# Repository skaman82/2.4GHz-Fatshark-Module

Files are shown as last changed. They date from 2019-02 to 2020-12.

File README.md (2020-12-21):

BUILD LOG: https://github.com/skaman82/2.4GHz-Fatshark-Module/wiki </br> </br>
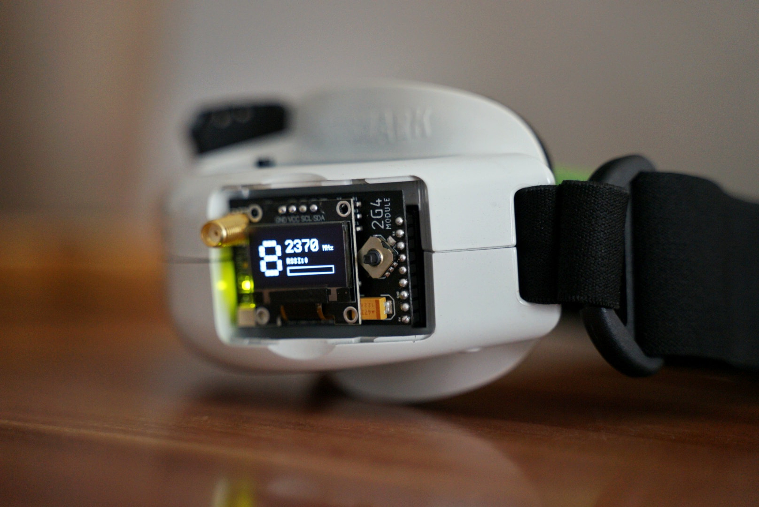
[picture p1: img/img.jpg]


# 2.4GHz-Fatshark-Module
RX28 based Fatshark RX module

- 8 channels (2414, 2432, 2450, 2468, 2490, 2510, 2390, 2370 MHz)
- RSSI display
- Fatshark button control
- Bandscan
- Finder mode
- RSSI calibration
- OSD menus
- OLED screen

Tested with following VTX models:</br>
• TBS Unify 2G4</br>
• Lawmate 2.4</br>
• FuriousFPV 2.4 VTX</br>
• Cheap low power chinese transmitter modules </br>
(no audio compatibility issues unlike the latest RX 2.4 module on the market)

# OPERATION
<b>HOME SCREEN:</b> You can change the channels by pressing the UP/DOWN keys - it works also with the google buttons (if the feature is active). If using the joystick you have to press UP/DOWN once to bring the OSD up - then you can change the channel. After no button press is registered the OSD will automatically disappear. </br>
</br>
By pressing the CENTER button you can bring up the <b>MENU</b>. With UP/DOWN you can switch between different menu items. Select EXIT to return to the home screen.</br>
</br>
<b>GOGGLE CONTROL:</b> Enables fatshark button control.</br>
</br>
<b>BANDSCAN:</b> Scans all channels and displays the RSSI values in a graph.</br>
</br>
<b>LOCK MODE:</b> If activated (lock icon in the home screen) the module will lock up after approx. 10 seconds. All controls are disabled to prevent chanel changes on acidental button press. You can temporarily UNLOCK the module by pressing the CENTER button for 3-5 seconds (the lock icon will open). After unlocking the module it will return to locked state after approx. 10 seconds.</br>
</br>
<b>FIND MODE:</b>Will show the RSSI value in a BAR (oled) or a plot (OSD). Depending on the RSSI value the beeper will beep more often and the OSD LED will blink as well indicating the direction. You can change the channel in the FIND MODE - so be sure you have the correct one. Use a directional antenna to find your model with this function.</br>
</br>
<b>AUTOSEARCH:</b> Press the CENTER button for 2 seconds to call the autosearch function. Autosearch will find the strongest channel and switch to it automatically.</br>
</br>
<b>CALIBRATION:</b> You have to run calibration to have the correct RSSI values. Just follow the instructions in the wizzard.</br>

# UPDATING THE FIRMWARE
You will need a FTDI to USB adapter to upload the module firmware. You may need to install the FTDI driver for it. Set the FTDI to 5V.

Steps to upload new firmware
1. Install Arduino IDE
2. Install the Arduino Libraries from the "Libs" folder.
3. Install the MightyCore hardware package from here: https://github.com/MCUdude/MightyCore (just follow the instructions)
4. Download the firmware and open the Code.INO file from the "Code" folder in Arduino
5. Select the hardware settings in Arduino IDE as shown in the image below
6. Connect the FTDI tool according to the plug pinout as shown in the picture and select the COM port in Arduino IDE
7. If you have the rev 06 PCB open the JUMP1 jumper on the PCB to upload code (solder it together after your upload is done).
8. Upload the code </br>
YOU ARE DONE :)

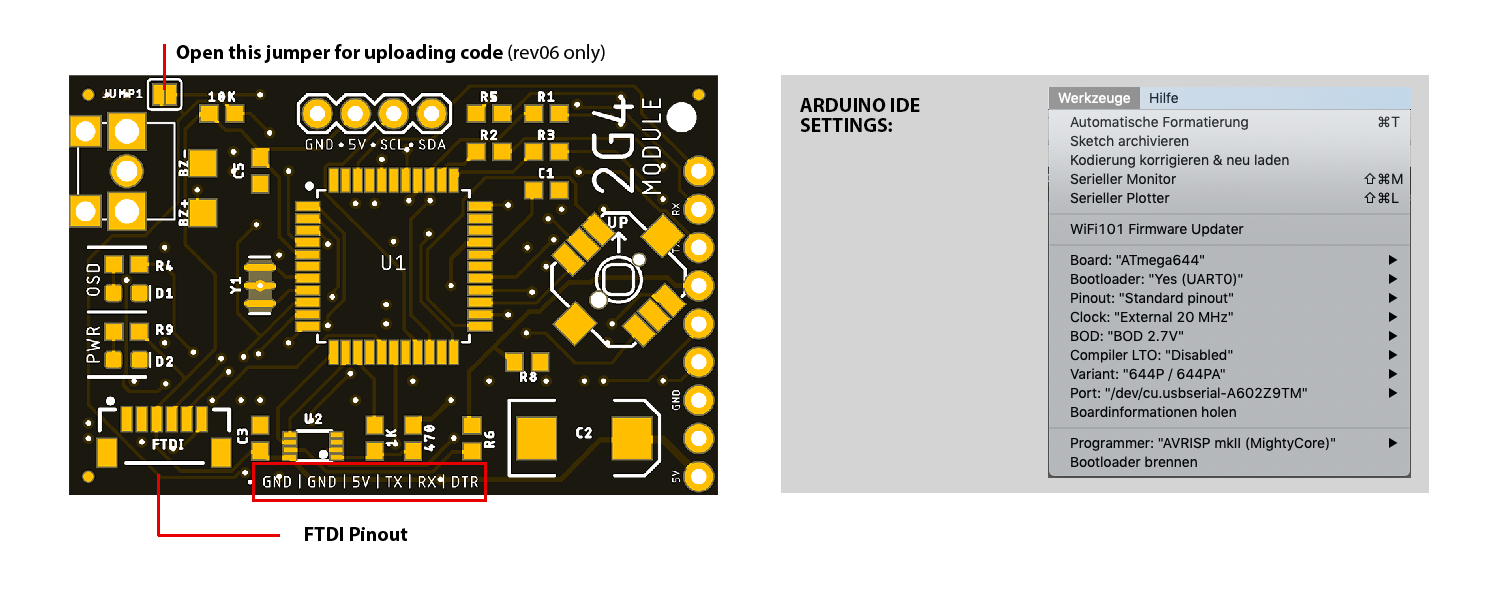
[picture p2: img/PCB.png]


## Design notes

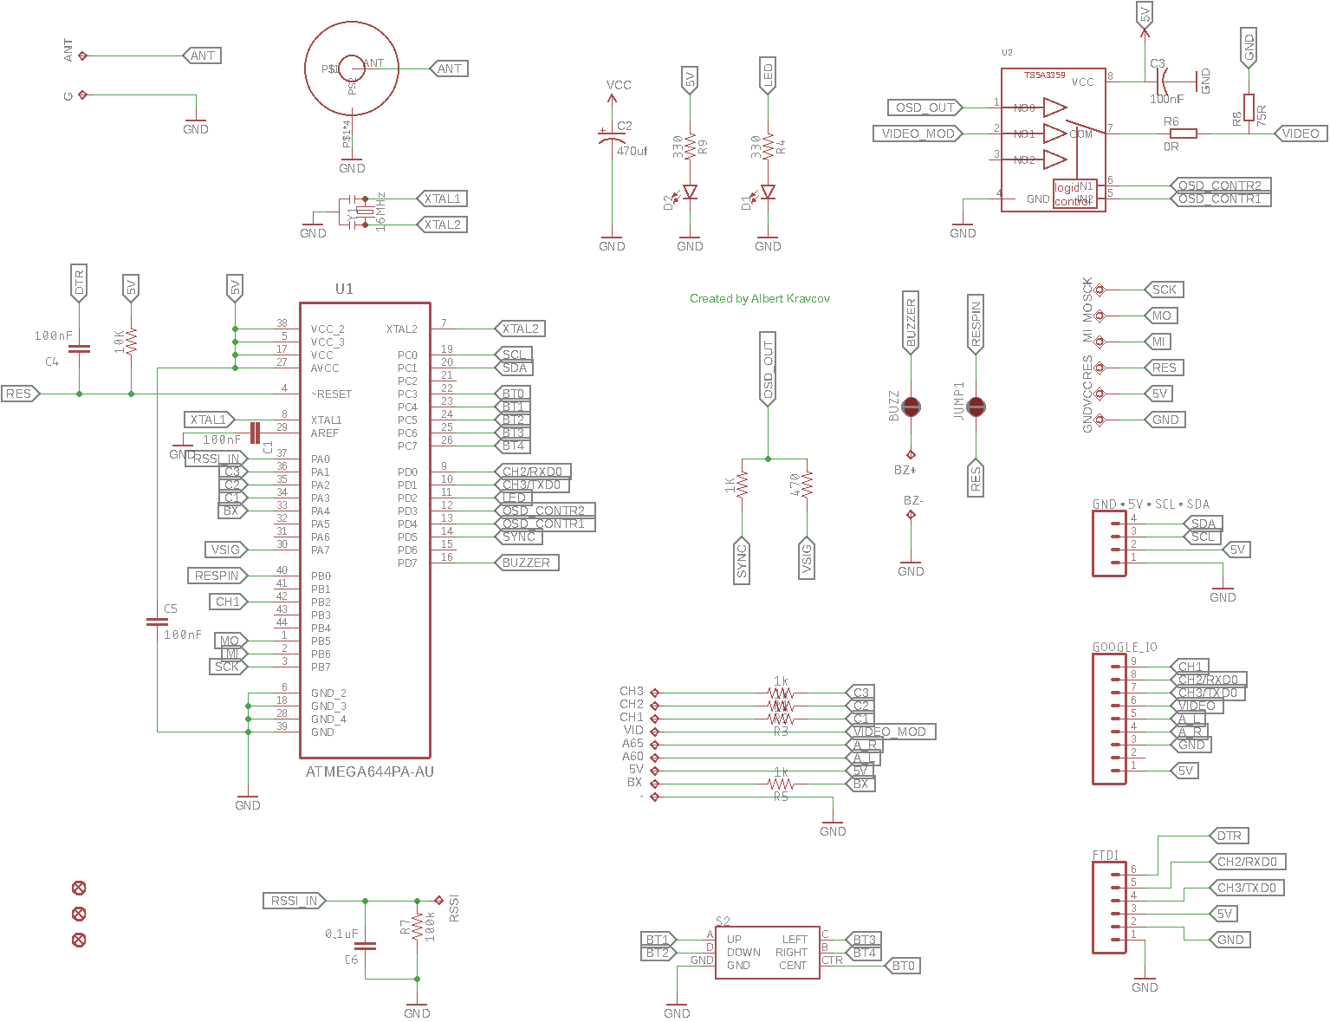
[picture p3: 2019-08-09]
img/schematic rev06.png

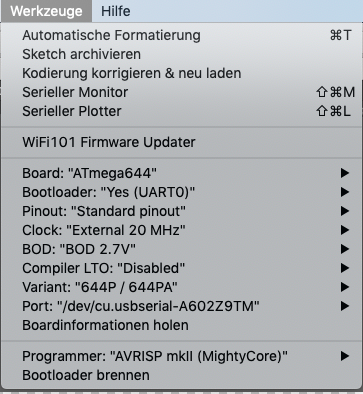
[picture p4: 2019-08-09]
img/arduino_settings.png

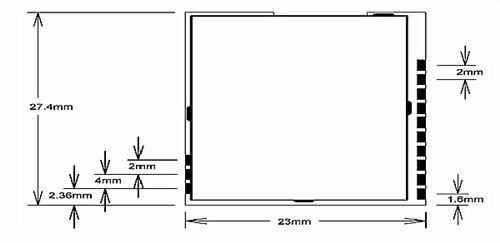
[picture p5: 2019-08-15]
Documents/RX2189 -90db EOL no rssi/HT19IRYFRXdXXagOFbXS.jpg

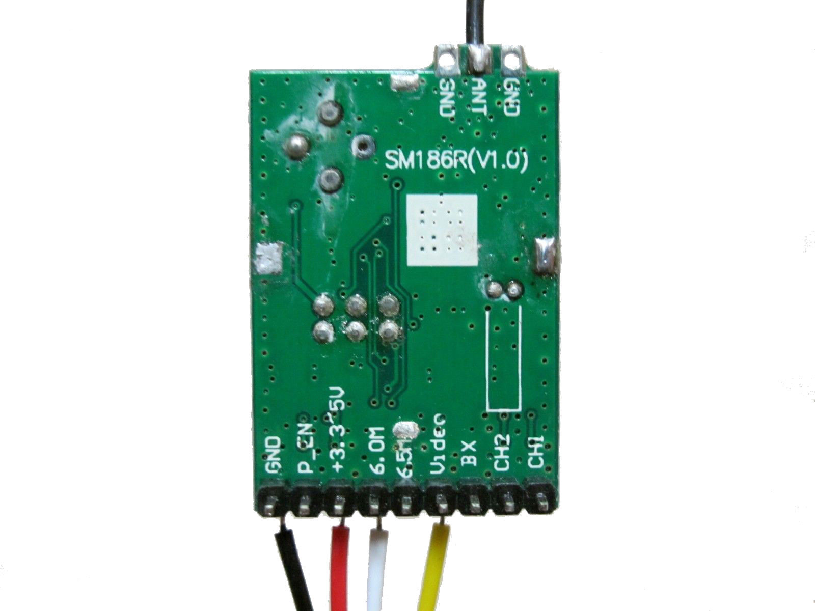
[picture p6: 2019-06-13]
Documents/SM186R -90db no rssi/s-l1600.jpg

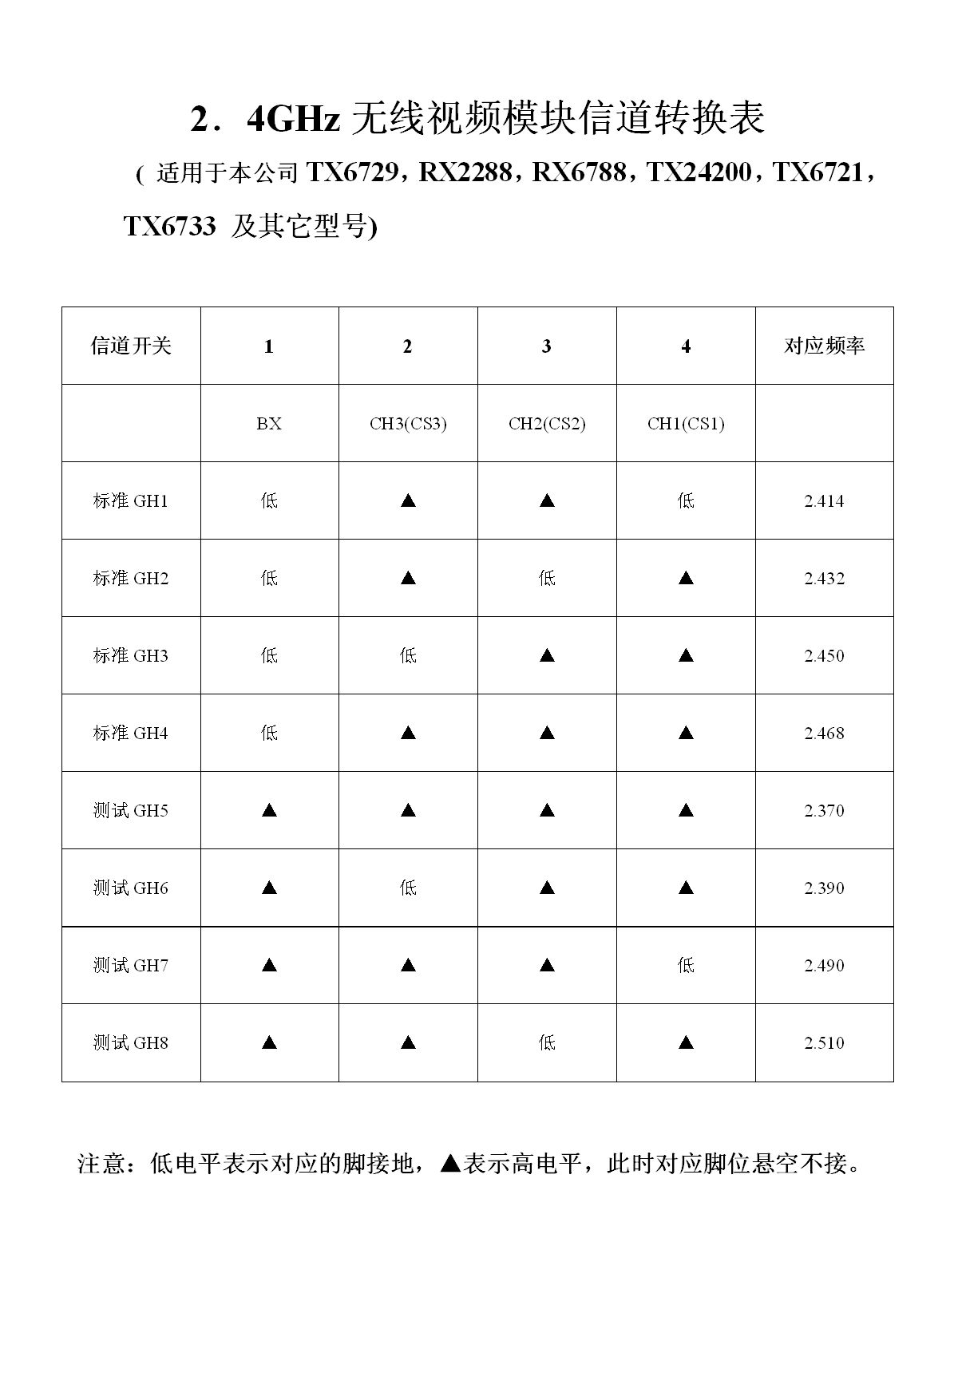
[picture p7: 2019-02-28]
Documents/RX228D -90db VID only - not compatible/2.4G信道表.jpg

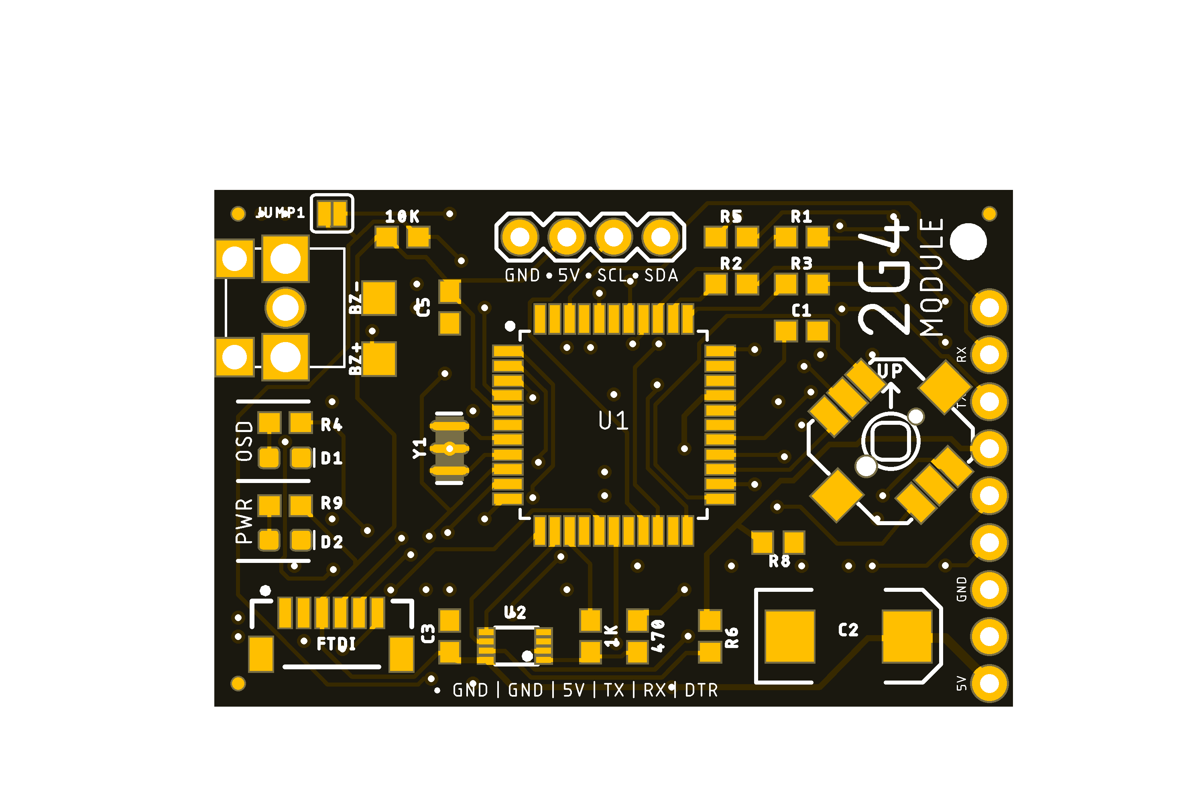
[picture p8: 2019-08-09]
pcb/module S-RX28_rev06 t.png

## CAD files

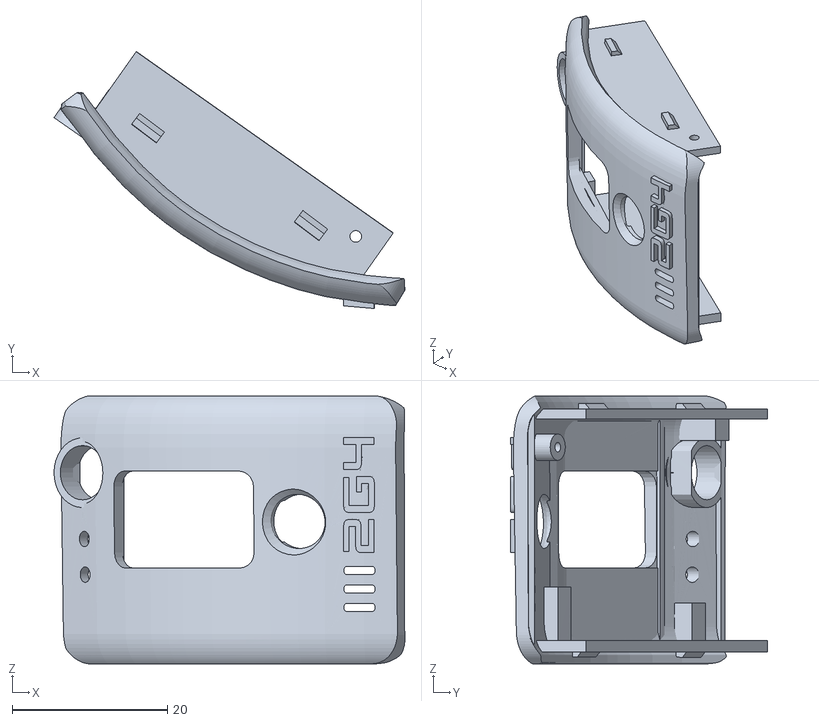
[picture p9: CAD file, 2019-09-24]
Cover/Module_door_V2.stl
45.3 x 33.2 x 34.5

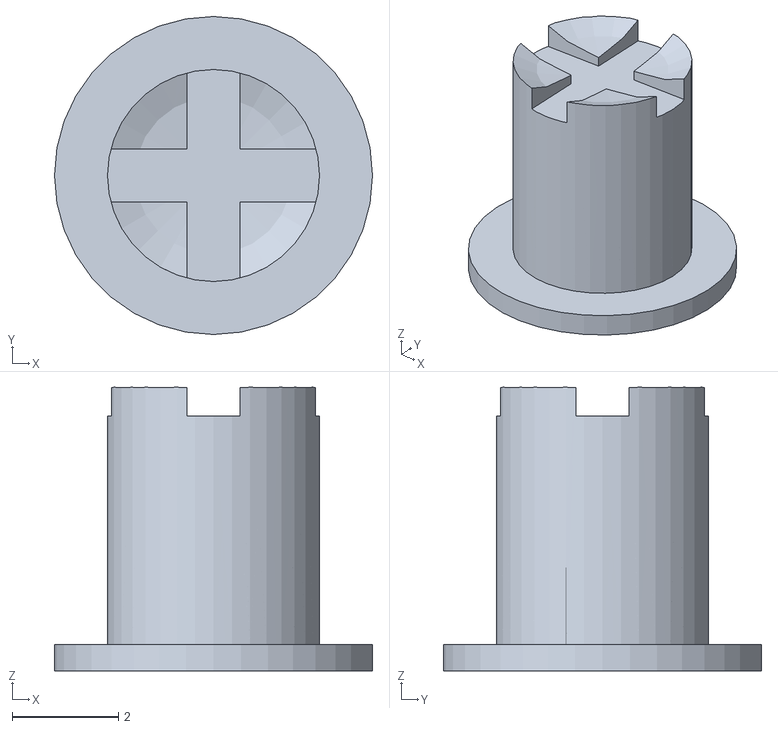
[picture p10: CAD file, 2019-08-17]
Cover/Module_door_button.stl
6.00 x 6.00 x 5.35

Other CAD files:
Cover/Module_door_V1.stl

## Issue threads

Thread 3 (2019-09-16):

Part list

Scavanger, 2019-09-16:
Hey, great project.
A complete partlist would be very helpful, especially display (Geekcreit 0.96" oled i2c, I guess), 5 way switch and SMA plug.
Thanks!

skaman82, 2019-09-19:
Thanks, you can find the complete list in the Wiki.

Closed 2019-09-19.

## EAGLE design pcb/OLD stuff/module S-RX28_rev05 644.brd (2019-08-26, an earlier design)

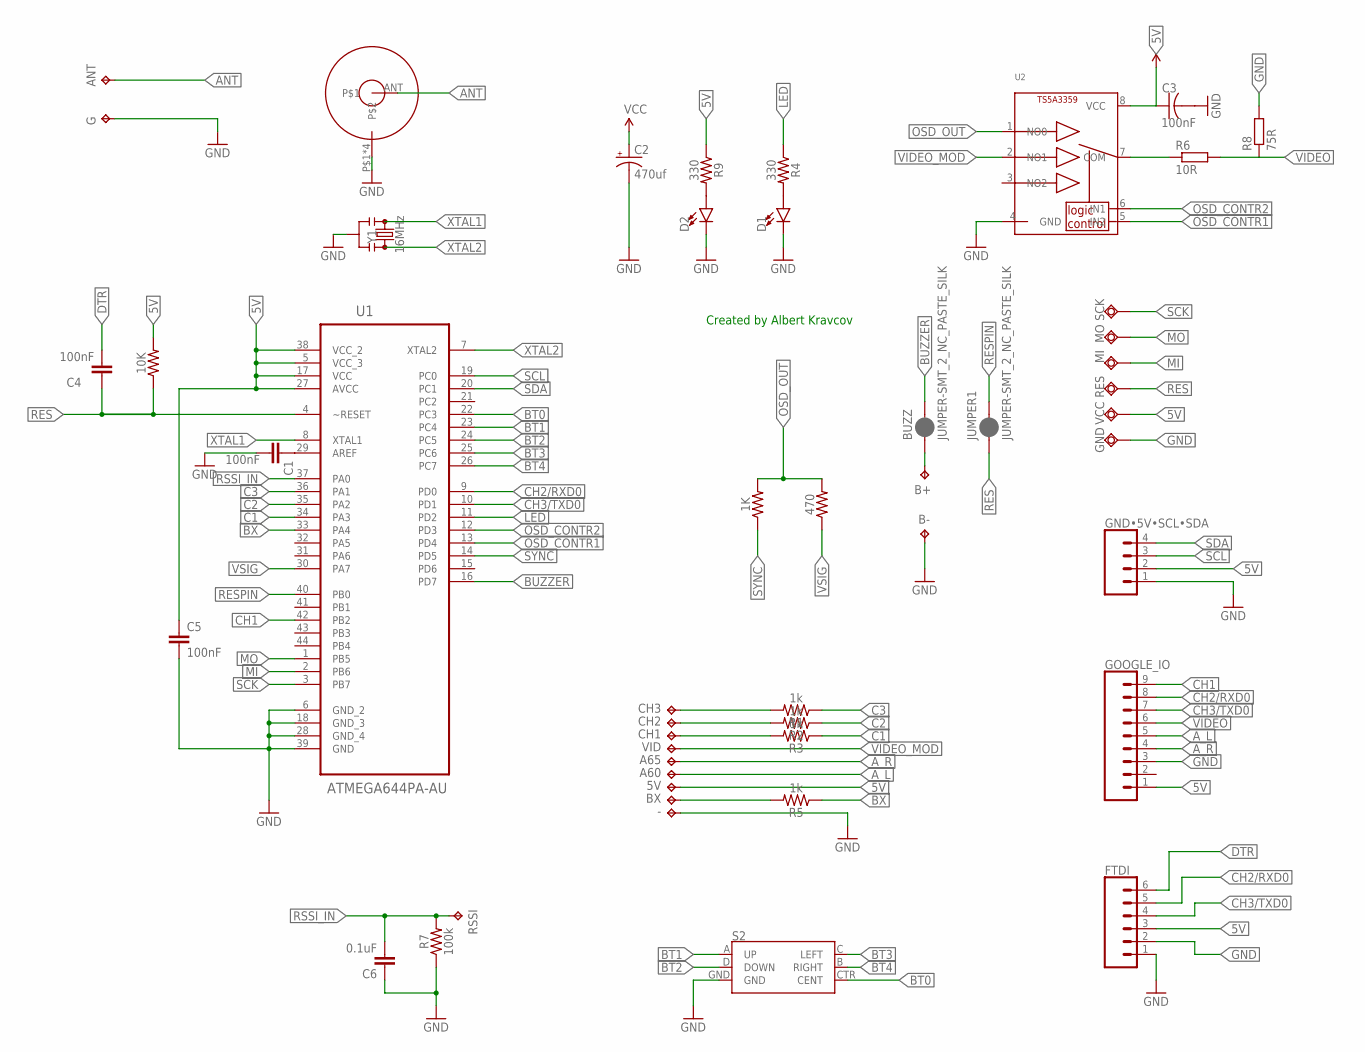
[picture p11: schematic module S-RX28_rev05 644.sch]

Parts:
1K, 10K, 470: 0.27OHM-0603-1/10W-1%; 0603
5V: TPTP15SQ; TP15SQ
-: TPTP15SQ; TP15SQ
A60, A65: TPTP15SQ; TP15SQ
ANT: TPTP15R; TP15R
B+: TPTP17SQ; TP17SQ
B-: TPTP17SQ; TP17SQ
BUZZ: JUMPER-SMT_2_NC_PASTE_SILK; SMT-JUMPER_2_NC_PASTE_SILK
BX: TPTP15SQ; TP15SQ
C1, C4, C5: 100nF; 0603
C2: 470uf; EIA7343
C3: 100nF; C0603
C6: 0.1uF; 0603
CH1, CH2, CH3: TPTP15SQ; TP15SQ
D1, D2: LED0603; LED-0603
FTDI: CONN_06SMD-1MM; 1X06-1MM
G: TPTP15SQ; TP15SQ
GND: GND; B1,27
GND•5V•SCL•SDA: CONN_04; 1X04
GOOGLE_IO: CONN_09; 1X09
JUMPER1: JUMPER-SMT_2_NC_PASTE_SILK; SMT-JUMPER_2_NC_PASTE_SILK
MI: TPSQB1,27; B1,27
MO: TPSQB1,27; B1,27
R1, R2, R3, R5: 1k; 0603
R4, R9: 330; 0603
R6: 10R; R0603
R7: 100k; 0603
R8: 75R; R0603
RES: TPSQB1,27; B1,27
RSSI: TPTP15SQ; TP15SQ
S2: JOYSTICK_MINI
SCK: TPSQB1,27; B1,27
U1: ATMEGA644PA-AU; QFP80P1200X1200X120-44N
U2: TS5A3359; VFSOP-8
U$1: SMA_ANTENNA; SMA_CONNECTOR
VCC: TPSQB1,27; B1,27
VID: TPTP15SQ; TP15SQ
Y1: 16MHz; RESONATOR-SMD-3.2X1.3

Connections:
5V: 5V.TP, 10K.2, C2.A (+), C3.1, C5.1, FTDI.3, GND•5V•SCL•SDA.2, GOOGLE_IO.1, R9.1, U1.5 (VCC_3), U1.17 (VCC), U1.27 (AVCC), U1.38 (VCC_2), U2.8 (VCC), VCC.TP
ANT: ANT.TP, U$1.ANT
AREF: C1.1, U1.29 (AREF)
A_L: A60.TP, GOOGLE_IO.5
A_R: A65.TP, GOOGLE_IO.4
BT0: S2.CTR (CENT), U1.22 (PC3)
BT1: S2.A (UP), U1.23 (PC4)
BT2: S2.D (DOWN), U1.24 (PC5)
BT3: S2.C (LEFT), U1.25 (PC6)
BT4: S2.B (RIGHT), U1.26 (PC7)
BUZZER: BUZZ.2, U1.16 (PD7)
BX: R5.1, U1.33 (PA4)
C1: R3.1, U1.34 (PA3)
C2: R2.1, U1.35 (PA2)
C3: R1.1, U1.36 (PA1)
CH1: GOOGLE_IO.9, U1.42 (PB2)
CH2/RXD0: FTDI.5, GOOGLE_IO.8, U1.9 (PD0)
CH3/TXD0: FTDI.4, GOOGLE_IO.7, U1.10 (PD1)
DTR: C4.2, FTDI.6
GND: -.TP, B-.TP, C1.2, C2.C (-), C3.2, C5.2, C6.1, D1.C, D2.C, FTDI.1, FTDI.2, G.TP, GND.TP, GND•5V•SCL•SDA.1, GOOGLE_IO.3, R7.1, R8.2, S2.GND, U1.6 (GND_2), U1.18 (GND_3), U1.28 (GND_4), U1.39 (GND), U2.4 (GND), U$1.P$1, U$1.P$2, U$1.P$3, U$1.P$4, Y1.2
LED: R4.1, U1.11 (PD2)
MI: MI.TP, U1.2 (PB6)
MO: MO.TP, U1.1 (PB5)
unnamed: CH3.TP, R1.2
unnamed: B+.TP, BUZZ.1
unnamed: CH2.TP, R2.2
unnamed: CH1.TP, R3.2
unnamed: BX.TP, R5.2
OSD_CONTR1: U1.13 (PD4), U2.5 (IN2)
OSD_CONTR2: U1.12 (PD3), U2.6 (IN1)
OSD_OUT: 1K.2, 470.2, U2.1 (NO0)
RED: D1.A, R4.2
RED1: D2.A, R9.2
RES: 10K.1, C4.1, JUMPER1.1, RES.TP, U1.4 (~RESET)
RESPIN: JUMPER1.2, U1.40 (PB0)
RSSI_IN: C6.2, R7.2, RSSI.TP, U1.37 (PA0)
SCK: SCK.TP, U1.3 (PB7)
SCL: GND•5V•SCL•SDA.3, U1.19 (PC0)
SDA: GND•5V•SCL•SDA.4, U1.20 (PC1)
SYNC: 1K.1, U1.14 (PD5)
VIDEO: GOOGLE_IO.6, R6.2, R8.1
VIDEOOUTPUT: R6.1, U2.7 (COM)
VIDEO_MOD: U2.2 (NO1), VID.TP
VSIG: 470.1, U1.30 (PA7)
XTAL1: U1.8 (XTAL1), Y1.1
XTAL2: U1.7 (XTAL2), Y1.3

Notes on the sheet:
Created by Albert Kravcov

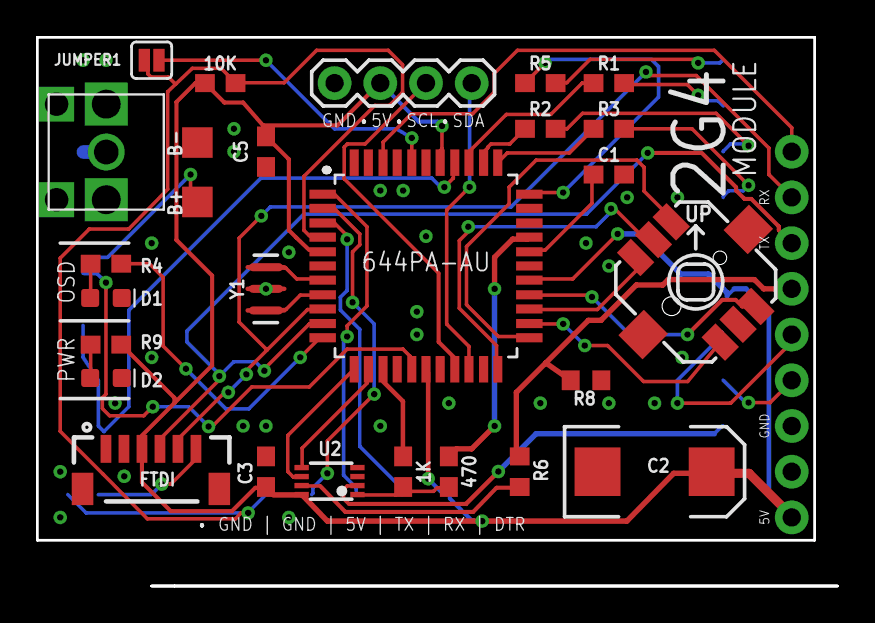
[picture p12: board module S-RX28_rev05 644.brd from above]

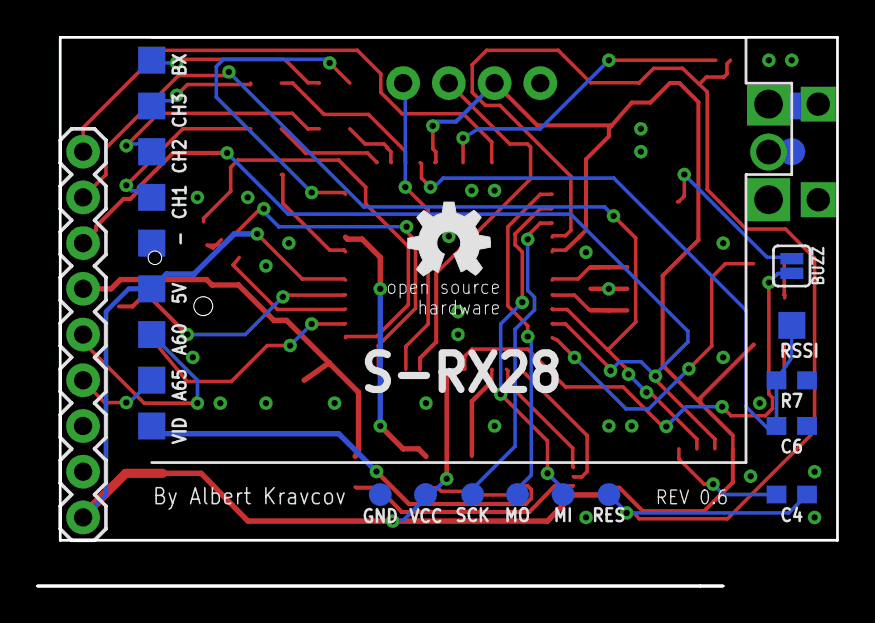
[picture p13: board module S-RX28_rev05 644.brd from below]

Board: 2 copper layers, 44.5 x 30.5 mm, 51 parts (24 on the bottom side), 46 nets.

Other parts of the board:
U$2: OSHW_5MM

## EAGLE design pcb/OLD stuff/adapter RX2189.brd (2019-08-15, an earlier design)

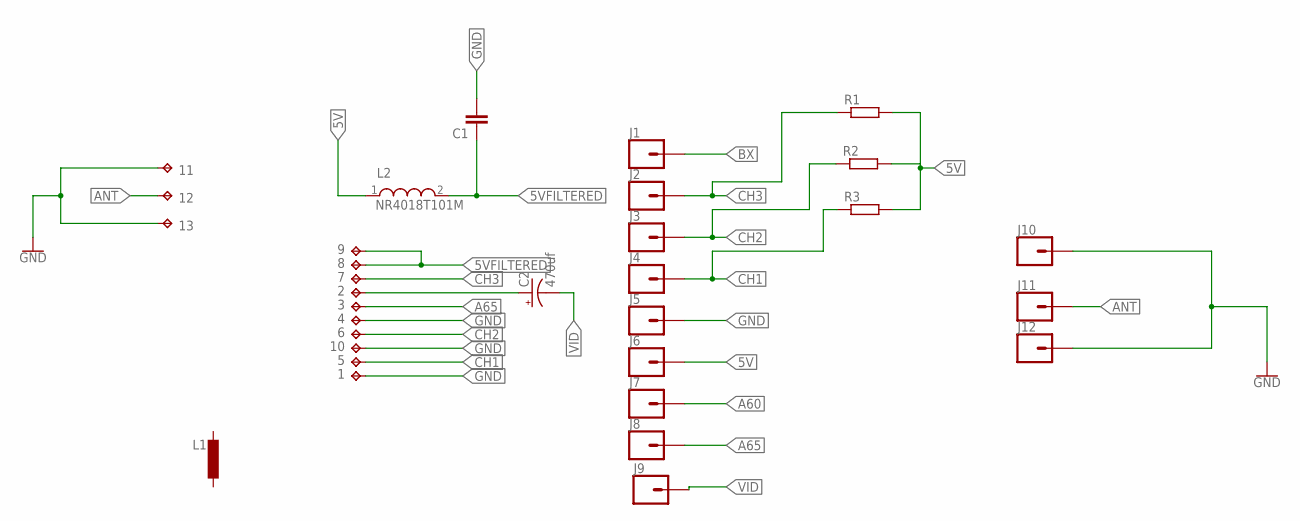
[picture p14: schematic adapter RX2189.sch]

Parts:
1, 2, 3, 4, 5, 6, 7, 8, 9, 10, 11, 12, 13: TPTP10SQ; TP10SQ
C1: C-EUC1206K; C1206K
C2: 470uf; EIA7343
J1, J2, J3, J4, J5, J6, J7, J8, J9, J10, J11, J12: CONN_01PTH_NO_SILK_KIT; 1X01NS_KIT
L1: L-EUWE-TPC; POWER-CHOKE_WE-TPC
L2: NR4018T101M; INDM4949X200N
R1, R2, R3: R-EU_R0603; R0603

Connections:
5V: J6.1, L2.1, R1.2, R2.2, R3.2
5VFILTERED: 8.TP, 9.TP, C1.1, L2.2
A60: J7.1
A65: 3.TP, J8.1
ANT: 12.TP, J11.1
BX: J1.1
CH1: 5.TP, J4.1, R3.1
CH2: 6.TP, J3.1, R2.1
CH3: 7.TP, J2.1, R1.1
GND: 1.TP, 4.TP, 10.TP, 11.TP, 13.TP, C1.2, J5.1, J10.1, J12.1
unnamed: 2.TP, C2.A (+)
VID: C2.C (-), J9.1

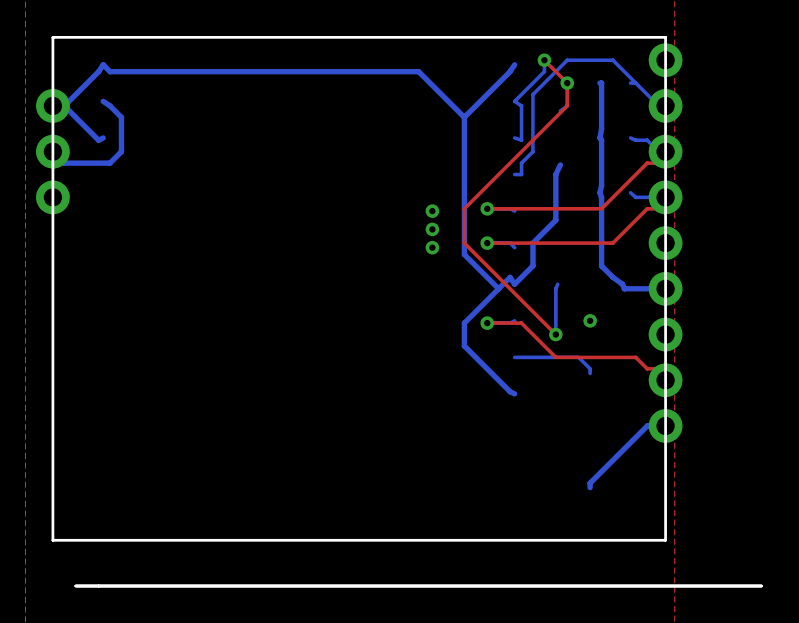
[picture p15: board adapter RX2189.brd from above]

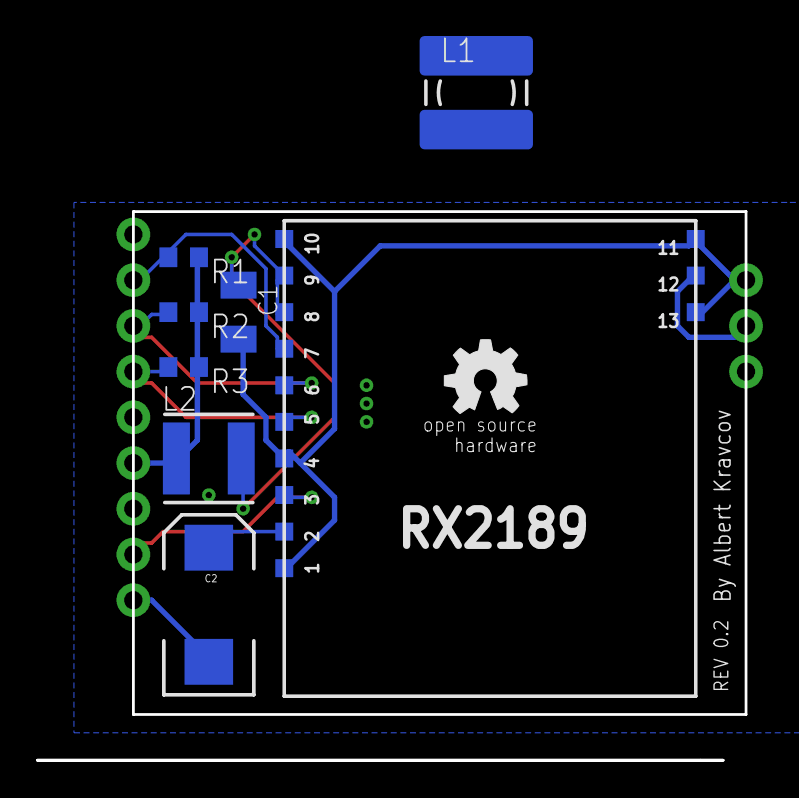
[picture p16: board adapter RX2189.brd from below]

Board: 2 copper layers, 34.0 x 27.9 mm, 33 parts (21 on the bottom side), 10 nets.

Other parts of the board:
U$2: OSHW_5MM

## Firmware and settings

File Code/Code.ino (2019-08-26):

// This Project is created by Albert Kravcov under GNU GPLv3 License
// 
//  The code uses some libraries created by others:
//  TV-OUT (VE) Library by 2017 nootropicdesign (MIT license)
//  U8glib
//  The U8glib code (http://code.google.com/p/u8glib/) is licensed under the terms of 
//  the new-bsd license (two-clause bsd license).


const char verId[7] = "v1.0"; //VERSION INFO

#include <TVout.h>
#include <font8x8.h>
#include <font6x8.h>
#include <font4x6.h>
#include "hardware.h"
#include "logo.h"
#include <Wire.h>
#include "U8glib.h"
#include <EEPROM.h>

//DISPLAY TYPE SELECTION
U8GLIB_SSD1306_128X64 u8g(U8G_I2C_OPT_DEV_0 | U8G_I2C_OPT_NO_ACK | U8G_I2C_OPT_FAST); // Fast I2C / TWI
//U8GLIB_SH1106_128X64 u8g(U8G_I2C_OPT_DEV_0 | U8G_I2C_OPT_FAST);  // Dev 0, Fast I2C / TWI

#include "bitmaps.h"

#define longpresstime         1000  // in ms
#define chanADDR                 1  // EEPROM Adress
#define lockmodeADDR             2  // EEPROM Adress
#define fscontrollADDR           3  // EEPROM Adress
#define displayADDR              4  // EEPROM Adress
#define RSSImaxADDR              5  // EEPROM Adress
#define RSSIminADDR              6  // EEPROM Adress
#define serialADDR               7  // EEPROM Adress

int channelvalueEEP;
int lockmodeEEP;
int fscontrollEEP;
int displayEEP;     //TODO: display settings
int RSSImaxEEP;     // RSSI calibration
int RSSIminEEP;     // RSSI calibration
int serialEEP;     // TODO serial communication
int max; //= 365; //0% RSSI
int min; // = 338; //100% RSSI
int findermode = 0;
int osd_mode = 0;
int menuactive = 0;
int BT_channel = 1;
int Old_FS_channel = 1;
int FS_channel = 1;
int FS_control = 0;
int SAVED_channel;
int ACT_channel = 1;
int BT_update = 0;
int pressedbut = 0;
int i_butt = 0;
word freq;
int lockmode;

byte voffset = 10;
byte rssiupdate = 0;
int refresh_osd = 0;
int refresh = 0;
int osd_timeout;
int lock_timeout;
byte display_setting; //NEW setting for display modes. 0 = ONLY OSD | 1 = OLED+OSD | 2 = ONLY OLED (will require a reboot)
byte serial_setting;


unsigned char x, y;
unsigned char originx = 5;
unsigned char originy = 70;
unsigned char plotx = originx;
unsigned char ploty = 40;

const unsigned char *chan_bitmaps[8] = { bitmap_one, bitmap_two, bitmap_three, bitmap_four, bitmap_five, bitmap_six, bitmap_seven, bitmap_eight };
const unsigned char *chan_bitmaps_osd[8] = { bitmap_one_OSD, bitmap_two_OSD, bitmap_three_OSD, bitmap_four_OSD, bitmap_five_OSD, bitmap_six_OSD, bitmap_seven_OSD, bitmap_eight_OSD };

typedef struct {
  int freq;
  int bx;
  int ch1;
  int ch2;
  int ch3;
} channel_t;

channel_t rx28_chan_table[8] = {
  { 2414, LOW, LOW, HIGH, HIGH },
  { 2432, LOW, HIGH, LOW, HIGH },
  { 2450, LOW, HIGH, HIGH, LOW },
  { 2468, LOW, HIGH, HIGH, HIGH },
  { 2490, HIGH, LOW, HIGH, HIGH },
  { 2510, HIGH, HIGH, LOW, HIGH },
  { 2390, HIGH, HIGH, HIGH, LOW },
  { 2370, HIGH, HIGH, HIGH, HIGH }
};


TVout TV;

void setup() {
  // TODO
  //digitalWrite(RST_pin, HIGH); // pull reset pin high

  // assign default color value
  if ( u8g.getMode() == U8G_MODE_R3G3B2 ) {
    u8g.setColorIndex(255);     // white
  }
  else if ( u8g.getMode() == U8G_MODE_GRAY2BIT ) {
    u8g.setColorIndex(3);         // max intensity
  }
  else if ( u8g.getMode() == U8G_MODE_BW ) {
    u8g.setColorIndex(1);         // pixel on
  }
  else if ( u8g.getMode() == U8G_MODE_HICOLOR ) {
    u8g.setHiColorByRGB(255, 255, 255);
  }

  pinMode(LED_pin,      OUTPUT); //LED
  pinMode(OSD_ctr1,     OUTPUT); //ctrl1
  pinMode(OSD_ctr2,     OUTPUT); //ctrl2
  pinMode(CH1_pin,      OUTPUT); //module c1
  pinMode(CH2_pin,      OUTPUT); //module c2
  pinMode(CH3_pin,      OUTPUT); //module c3
  pinMode(BX_pin,       OUTPUT); //module BX (connect to ch3 on RX2189)
  pinMode(FS_pin1,      INPUT); //google c1
  pinMode(FS_pin2,      INPUT); //google c2
  pinMode(FS_pin3,      INPUT); //google c3
  pinMode(ButtonCenter, INPUT_PULLUP); //Button
  pinMode(ButtonLeft,   INPUT_PULLUP); //Button left
  pinMode(ButtonRight,  INPUT_PULLUP); //Button right
  pinMode(ButtonUp,     INPUT_PULLUP); //Button left
  pinMode(ButtonDown,   INPUT_PULLUP); //Button right
  pinMode(BUZZ,         OUTPUT); //Buzzer
  //pinMode(RST_pin,      OUTPUT); // NEW reset

#ifdef RSSI_mod
  pinMode(RSSI_pin, INPUT);
#endif

  channelvalueEEP = EEPROM.read(chanADDR);
  lockmodeEEP = EEPROM.read(lockmodeADDR);
  fscontrollEEP = EEPROM.read(fscontrollADDR);
  displayEEP = EEPROM.read(displayADDR); //TODO
  RSSImaxEEP = EEPROM.read(RSSImaxADDR)  * 2;
  RSSIminEEP = EEPROM.read(RSSIminADDR)  * 2;
  serialEEP = EEPROM.read(serialADDR); //TODO

  max = RSSImaxEEP;
  min = RSSIminEEP;

  if (fscontrollEEP >= 2) {
    fscontrollEEP = 0; //setting the  default state of no valid value
  }

  if (lockmodeEEP >= 2) {
    lockmodeEEP = 0; //setting the  default state of no valid value
  }

  if (channelvalueEEP <= 8)
  {
    SAVED_channel = channelvalueEEP;
  }
  if (channelvalueEEP > 8)
  {
    SAVED_channel = 1; //setting the  default state of no valid value
  }

  if (displayEEP > 2)
  {
    display_setting = 1; //setting the  default state of no valid value
  }

  if (serialEEP > 2)
  {
    serial_setting = 0; //setting the  default state of no valid value
  }

  //TODO>
  display_setting = 1; //just for testing 0 = ONLY OSD | 1 = OLED+OSD | 2 = ONLY OLED

  serial_setting = 0;

  //TODO>
  if (serial_setting == 1) {
    fscontrollEEP = 0; //disable FS button control
    Serial.begin(9600);
  }

  clearOLED();

  if (display_setting >= 1) {
    showlogo();

    if (display_setting == 2) {
      delay(2000);
    }
  }


  if (display_setting <= 1) {  //NEW
#ifdef PAL_FORMAT
    TV.begin(_PAL, 128, 96); //original 128x96px, 160x120max (146x120)
#endif
#ifdef NTSC_FORMAT
    TV.begin(_NTSC, 128, 90);
#endif
    TV.delay_frame(1);
    display.output_delay = 55; //move the whole screen vertically

    TV.clear_screen();
    TV.bitmap(5, (20 + voffset), logo);

    osd_timeout = 100; //looptime setting for osd timeout
    lock_timeout = 300; //looptime setting for lockmode timeout
  }
  else {
    osd_timeout = 0; //looptime setting for osd timeout
    lock_timeout = 600; //looptime setting for lockmode timeout
  }

  if (display_setting <= 1) {

    digitalWrite(OSD_ctr1, HIGH);
    digitalWrite(OSD_ctr2, LOW);
    digitalWrite(LED_pin, HIGH);

    TV.select_font(font6x8);
    TV.print(15, (50 + voffset), "2G4 MODULE ");
    TV.print(verId);
    TV.select_font(font4x6);
    TV.print(29, (69 + voffset), "#RUININGTHEHOBBY");
    TV.delay(3000);
    TV.tone(500, 200);
    TV.clear_screen();

    osd_mode = 1;
  }
  else {
    tone(BUZZ, 500, 200);
    osd_mode = 0;
  }

  clearOLED();

  menuactive = 0;
  lockmode = 0;

}


void clearOLED()
{
  u8g.firstPage();
  do
  {
  }
  while ( u8g.nextPage() );

}

void showlogo()
{
  u8g.firstPage();
  do
  {
    // splashscreen goes here
    u8g.drawBitmapP(10, 10, 14, 18, logo_OLED);
    u8g.setFont(u8g_font_5x7r);
    u8g.setPrintPos(31, 45);
    u8g.print("2G4 MODULE ");
    u8g.print(verId);
  }
  while (u8g.nextPage());
}

byte buttoncheck()
{
  int i_butt = 0;
  byte buttonz = 0;
  if (digitalRead(ButtonCenter) != 1)
  {
    while (digitalRead(ButtonCenter) != 1)
    {
      delay(2);
      i_butt++;
    }
    buttonz = 1;

    if (i_butt > (longpresstime / 2))
    {
      buttonz += 5;
    }
  }

  if (digitalRead(ButtonLeft) != 1)
  {
    while (digitalRead(ButtonLeft) != 1)
    {
      delay(2);
      i_butt++;
    }
    buttonz = 2;
  }

  if (digitalRead(ButtonRight) != 1)
  {
    while (digitalRead(ButtonRight) != 1)
    {
      delay(2);
      i_butt++;
    }
    buttonz = 3;
  }

  if (digitalRead(ButtonUp) != 1)
  {
    while (digitalRead(ButtonUp) != 1)
    {
      delay(2);
      i_butt++;
    }
    buttonz = 4;
  }

  if (digitalRead(ButtonDown) != 1)
  {
    while (digitalRead(ButtonDown) != 1)
    {
      delay(2);
      i_butt++;
    }
    buttonz = 5;
  }

  pressedbut = buttonz;
  return buttonz;
}


void fs_buttons() {
  // FS Button mapping:
  //CH1: p1-LOW,  p2-LOW,   p3-LOW
  //CH2: p1-HIGH, p2-LOW,   p3-LOW
  //CH3: p1-LOW,  p2-HIGH,  p3-LOW
  //CH4: p1-HIGH, p2-HIGH,  p3-LOW
  //CH5: p1-LOW,  p2-LOW,   p3-HIGH
  //CH6: p1-HIGH, p2-LOW,   p3-HIGH
  //CH7: p1-LOW,  p2-HIGH,  p3-HIGH
  //CH8: p1-HIGH, p2-HIGH,  p3-HIGH

  int chan = 0;

  if (digitalRead(FS_pin1) == HIGH)
    chan = 1;

  if (digitalRead(FS_pin2) == HIGH)
    chan |= 1 << 1;

  if (digitalRead(FS_pin3) == HIGH)
    chan |= 1 << 2;

  FS_channel = chan + 1;
}


void control() {
  if (pressedbut == 1) {

    if (lockmode == 0) {
      if (display_setting <= 1) {
        TV.tone(800, 80);
      }
      else {
        tone(BUZZ, 800, 80);
      }
    }
    else {
      if (display_setting <= 1) {
        TV.tone(100, 100);
        TV.delay(200);
        TV.tone(100, 100);
      }
      else {
        tone(BUZZ, 100, 100);
        delay(200);
        tone(BUZZ, 100, 100);
      }
    }


    if (lockmode == 0) {
      if (menuactive == 0) {
        if (display_setting <= 1) {
          TV.clear_screen();
        }
        menuactive = 1;
        menu();

      }
      else if (menuactive == 1) {
        if (display_setting <= 1) {
          TV.fill(BLACK);
          TV.delay(10);
        }
        //return;
      }
    }


  }

  if (pressedbut == 2) {

    if (lockmode == 0) {
      if (display_setting <= 1) {
        TV.tone(800, 80);
      }
      else {
        tone(BUZZ, 800, 80);
      }
    }
    else {
      if (display_setting <= 1) {
        TV.tone(100, 100);
        TV.delay(200);
        TV.tone(100, 100);
      }
      else {
        tone(BUZZ, 100, 100);
        delay(200);
        tone(BUZZ, 100, 100);
      }
    }
    if (lockmode == 0) {
      if (menuactive == 0) {
        Old_FS_channel = FS_channel;
        BT_update = 1;
        FS_control = 0;

        if (osd_mode == 1) {
          refresh_osd = 1; //reset  OSD timer
          refresh = 1; //reset  lock timer

          if (BT_channel >= 2) {
            BT_channel -= 1;
          }

          else {
            BT_channel = 8;
          }
        }

        else {
          callOSD();
        }
      }
      else {
        if (display_setting <= 1) {
          TV.clear_screen();
        }
        callOSD();
      }
    }
  }

  if (pressedbut == 3) {

    if (lockmode == 0) {
      if (display_setting <= 1) {
        TV.tone(800, 80);
      }
      else {
        tone(BUZZ, 800, 80);
      }
    }
    else {
      if (display_setting <= 1) {
        TV.tone(100, 100);
        TV.delay(200);
        TV.tone(100, 100);
      }
      else {
        tone(BUZZ, 100, 100);
        delay(200);
        tone(BUZZ, 100, 100);
      }
    }

    if (lockmode == 0) {
      if (menuactive == 0) {
        Old_FS_channel = FS_channel;
        BT_update = 1;
        FS_control = 0;

        if (osd_mode == 1) {

          refresh_osd = 1; //reset  osd timer
          refresh = 1; //reset timer

          if (BT_channel <= 7) {
            BT_channel += 1;
          }

          else {
            BT_channel = 1;
          }
        }

        else {
          callOSD();
        }
      }
      else {
        if (display_setting <= 1) {
          TV.clear_screen();
        }
        callOSD();
      }
    }
  }

  if (pressedbut == 6) {

    if (lockmode == 1) {
      lockmode = 0;
      menuactive = 0;
      if (display_setting <= 1) {
        TV.tone(600, 400);
      }
      else {
        tone(BUZZ, 600, 400);
      }

      callOSD();
      return;
    }
    else {
      if (display_setting <= 1) {
        TV.clear_screen();
      }
      autosearch();
    }
  }
}


//>>RXUPDATE
void rx_update() {

  if  (FS_channel != Old_FS_channel) { //if a change is detected (FS buttons)
    BT_update = 0;
    FS_control = 1;
    if (osd_mode == 0) { //call OSD
      callOSD();
      Old_FS_channel = FS_channel; //store active FS button state to detect a change
    }
  }

  if (BT_update == 1) { //if a change is detected (module button)
    ACT_channel = BT_channel;
  }

  if (BT_update == 0) {

    if  ((SAVED_channel != 0) && (FS_control == 0)) { //if a saved channel is found, seti it at startup
      ACT_channel = SAVED_channel;
    }
    else {
      ACT_channel = FS_channel; //or set the active channel according to FS button position
    }
  }

  else {
    ACT_channel = BT_channel; //if nothing from above applies, set tha active channel acording to module button state
  }
}

void channeltable() {
  if (ACT_channel < 1 || ACT_channel > 8)
    ACT_channel = 1;

#ifdef RX28 //RX28 receiver channel settings
  channel_t ch = rx28_chan_table[ACT_channel - 1];
#endif


  freq = ch.freq;
  digitalWrite(BX_pin, ch.bx); //BX
  digitalWrite(CH1_pin, ch.ch1); //1
  digitalWrite(CH2_pin, ch.ch2); //2
  digitalWrite(CH3_pin, ch.ch3); //3

}

void callOSD() {

  if (osd_mode != 1) {
    osd_mode = 1;
    return;
  }
  else {
    return;
  }
}

void osd() {

  if (osd_mode == 1) {
    if (display_setting <= 1) {
      digitalWrite(OSD_ctr1, HIGH);
      digitalWrite(OSD_ctr2, LOW);
      if (findermode == 0) {
        digitalWrite(LED_pin, HIGH);
      }
    }
  }

  else if (osd_mode == 0) {
    digitalWrite(OSD_ctr1, LOW);
    digitalWrite(OSD_ctr2, HIGH);
    digitalWrite(LED_pin, LOW);
  }
  else {
    //osd_mode = 1;
  }
}



//MAIN LOOP ************************

void loop() {

  u8g.firstPage();
  do {
    buttoncheck();

    if (fscontrollEEP == 1) {
      if (lockmode == 0) {
        fs_buttons();
      }
    }

    control();
    rx_update();
    channeltable();
    runlocktimer();
    osd();

    if (display_setting <= 1) {
      //Main OSD code

      TV.select_font(font8x8);
      TV.print(58, (20 + voffset), freq);
      TV.select_font(font6x8);
      TV.println(95, (22 + voffset), "MHz");

      if (ACT_channel >= 1 && ACT_channel <= 8)
        TV.bitmap(18, (20 + voffset), chan_bitmaps_osd[ACT_channel - 1]);
    }

#ifdef RSSI_mod
    uint32_t rssi_value = _readRSSI();
    float percentage = map(rssi_value, max, min, 0, 100);
    if (percentage > 100) {
      percentage = 100;
    }
    else if (percentage < 0) {
      percentage = 0;
    }

    if (fscontrollEEP == 0) {


      //PLACEHOLDER FOR SERIAL CODE
      Serial.println(percentage, 0);
      Serial.println(ACT_channel);
    }

    if (display_setting <= 1) {
      TV.select_font(font4x6);
      //TV.draw_rect(58, (41 + voffset), 30, 8, BLACK, BLACK); //mask
      TV.print(58, (41 + voffset), "RSSI:");
      TV.println((percentage - 0), 0);

      if ((percentage < 100) && (percentage >= 10)) {
        TV.draw_rect(86, (41 + voffset), 4, 4, BLACK, BLACK); //cover the first RSSI number
      }

      else if (percentage < 10) {
        TV.draw_rect(82, (41 + voffset), 8, 4, BLACK, BLACK); //cover the second RSSI number
      }

      TV.draw_rect(58, (53 + voffset), 52, 8, WHITE, BLACK);
      TV.draw_rect(60, (55 + voffset), (percentage * 0.48) , 4, WHITE, WHITE);
    }

#endif


    if (display_setting <= 1) {
      if ((menuactive != 1) && (osd_mode == 1)) {
        //NEW OSD TIMER
        refresh_osd++ ;

        if (refresh_osd >= osd_timeout) {
          osd_mode = 0;

          TV.clear_screen();
          TV.tone(100, 150);

          //saving the last activechannel to EEPROM
          channelvalueEEP = ACT_channel;
          EEPROM.write(chanADDR, channelvalueEEP);
          refresh_osd = 0;
        }
        else {
          osd_mode = 1;
        }
      }
    }

    if (display_setting >= 1) {
      u8g.setFont(u8g_font_profont22r);
      u8g.setPrintPos(50, 26);
      u8g.print(freq);
      u8g.setFont(u8g_font_5x7r);
      u8g.print(" MHz");

#ifdef RSSI_mod
      u8g.setFont(u8g_font_5x7r);
      u8g.setPrintPos(50, 40);
      u8g.print("RSSI:");
      u8g.print(percentage, 0);
      u8g.drawBox(53, 48, (percentage * 0.60), 3); //
      u8g.drawFrame(50, 45, 66, 9);
      //u8g.setColorIndex(0);
      //u8g.drawVLine(53,48,5);
      //u8g.drawVLine(61,48,5);
      //u8g.drawVLine(69,48,5);
      //u8g.drawVLine(77,48,5);
      //u8g.drawVLine(85,48,5);
      //u8g.drawVLine(93,48,5);
      //u8g.drawVLine(101,48,5);
      //u8g.drawVLine(109,48,5);
      //u8g.setColorIndex(1);

#endif

      if (ACT_channel >= 1 && ACT_channel <= 8)
        u8g.drawBitmapP(12, 12, 4, 41, chan_bitmaps[ACT_channel - 1]);

      if ((lockmodeEEP == 1) && (lockmode == 1)) {
        u8g.drawBitmapP(109, 32, 2, 8, bitmap_lock);     //mini lock icon
      }
      else if ((lockmodeEEP == 1) && (lockmode == 0)) {
        u8g.drawBitmapP(109, 32, 2, 8, bitmap_lockopen);     //mini lock icon
      }
    }
  } while ( u8g.nextPage() );

}



//RSSI READOUT ************************ simple avg of 4 value

uint16_t _readRSSI() {

  rssiupdate++;
  volatile uint32_t sum = 0;
  sum = analogRead(RSSI_pin);
  sum += analogRead(RSSI_pin);
  sum += analogRead(RSSI_pin);
  sum += analogRead(RSSI_pin);
  return sum / 4;
}


//MAIN MENU ************************
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

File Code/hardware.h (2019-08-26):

//#define debug

#define RX28 //RX28 (S-RX28)
#define RSSI_mod //If RSSI mod is done on the rtc6711 chip (see datasheet)
#define PAL_FORMAT //PAL_FORMAT or NTSC_FORMAT for OSD (NTSC may not work)


//************V3 Hardware*******************
  #define CH1_pin      A3
  #define CH2_pin      A2
  #define CH3_pin      A1
  #define BX_pin       A4 
  #define RSSI_pin     A0
  #define FS_pin1      2
  #define FS_pin2      8 //RXD0
  #define FS_pin3      9 //TXD0
  #define ButtonCenter 19 
  #define ButtonLeft   21
  #define ButtonRight  20
  #define ButtonUp     23
  #define ButtonDown   22
  #define BUZZ         15 //OC2A
  #define LED_pin      10 
  #define OSD_ctr1     11
  #define OSD_ctr2     12
  //#define RST_pin       0 //NEW

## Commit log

2019-06-12 initial code commit
    [module S-RX28_rev3.3 644.brd, module S-RX28_rev3.3 644.sch]
2019-06-13 fixing menus and cleanup
    [Code.ino]
2019-06-13 added docs
    [module S-RX28_rev3.3 644.brd, module S-RX28_rev3.3 644.sch]
2019-06-14 lockmode & google button control EEPROM settings
2019-06-14 pin def
2019-06-20 new PCB revision
    [module S-RX28_rev05 644.brd, module S-RX28_rev05 644.sch]
2019-06-21 fixed button bug and starting code for new display setting
    [Code.ino, hardware.h]
2019-06-21 lockmode fix & new bitmaps
    [Code.ino, bitmaps.h]
2019-07-08 fix for calibration menu
    [Code.ino]
2019-08-08 added flashing LED in finder mode + google button fix
    [Code.ino, hardware.h]
2019-08-08 OLED calibration wizzard
2019-08-09 OSD Finder Mode + New PCB revision (with mounting hole)
    [adapter RX2189.brd, adapter RX2189.sch, module S-RX28_rev06 644.brd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]
2019-08-15 documentation update
    [adapter RX2189.brd, adapter RX2189.sch]
2019-08-15 change MIN/MAX in RSSI calibration to avoid confusion
    [Code.ino]
2019-08-17 module cover
    [Module_door_V1.stl, Module_door_button.stl]
2019-08-24 fixed autosearch + formatting
    [Code.ino]
2019-08-24 Update Code.ino
    new calibration process
2019-08-26 Updates
    • Autosearch bugfix and UI
    • Calibration UI improvements
    • Cleaning-up old files
    [adapter RX2189.brd, adapter RX2189.sch, module S-RX28_rev05 644.brd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]
2019-09-24 Slightly different module door for rev07+ PCBs
    [Module_door_V2.stl]

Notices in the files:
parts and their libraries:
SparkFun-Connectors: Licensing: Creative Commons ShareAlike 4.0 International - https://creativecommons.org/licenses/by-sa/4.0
